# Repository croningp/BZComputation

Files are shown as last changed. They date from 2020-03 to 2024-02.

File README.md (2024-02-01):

# A Programmable Hybrid Digital Chemical Information Processor based on the Belousov-Zhabotinsky Reaction



This repository consist of the hardware and specification of parts associated to the paper "A Programmable Hybrid Digital Chemical Information Processor based on the Belousov-Zhabotinsky Reaction".

Authors: Abhishek Sharma, Marcus Tze-Kiat Ng, Juan Manuel Parrilla Gutierrez, Yibin Jiang, Leroy Cronin*

School of Chemistry, The University of Glasgow, University Avenue, Glasgow G12 8QQ, United Kingdom

## Platform Overview
The periodicity of the oscillation of the BZ reaction is controlled via mechanical stimulus from the magnetics stirrers. On top of that, the coupling between two or more neighbouring cells are governed by the hydrodynamics through the interfacial stirrers.<br/>
The dimension of each cell was desgined in such a way that no apparent coupling between cells can be observed without activation of the interfacial stirrers.
<p align="center">
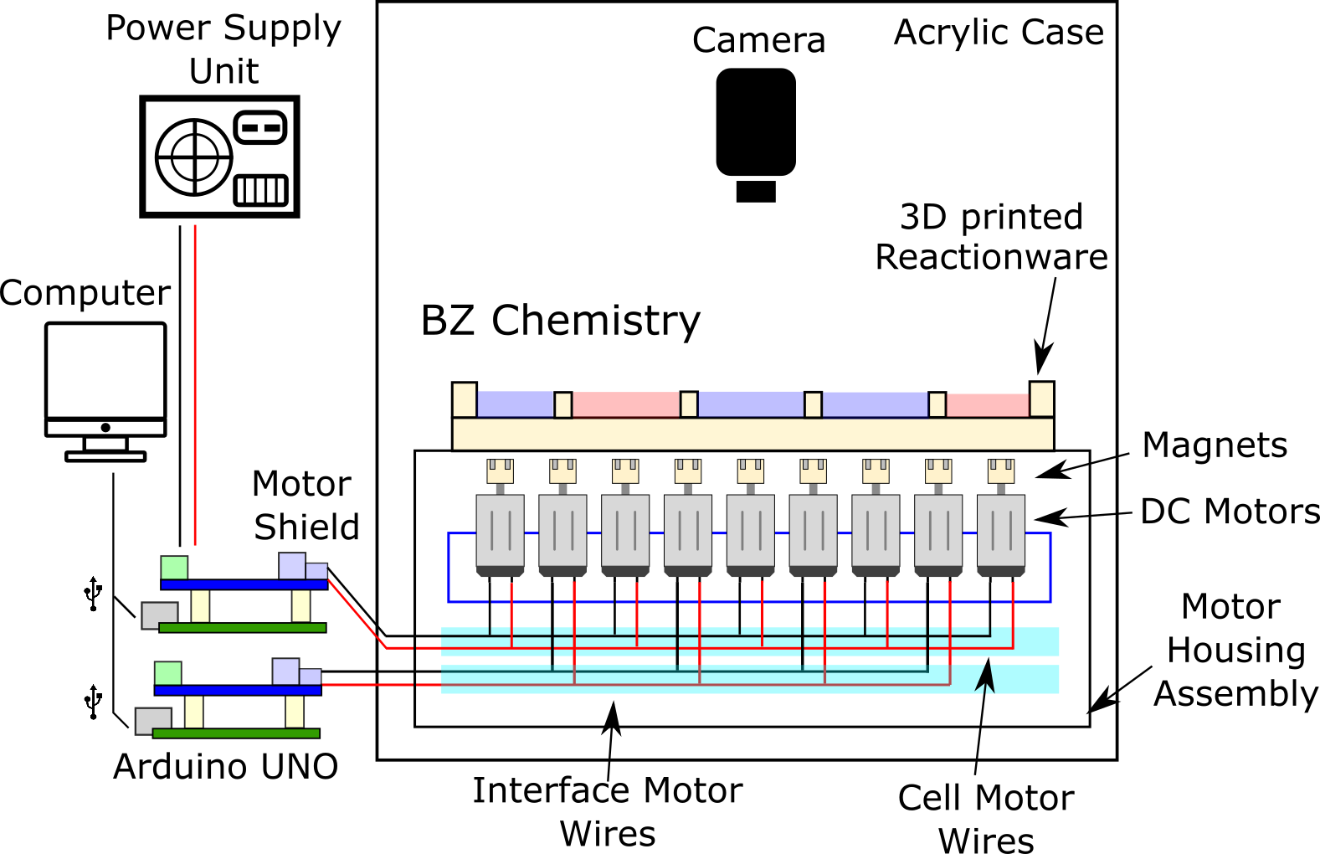
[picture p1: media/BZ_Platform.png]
  

Details regarding the hardware and the STLs of the 3D printed parts used for the experiments are provided in [hardware](https://github.com/croningp/BZComputation/blob/master/hardware/hardware.md).

## Basic Experimental Control Code example
```python
# Library imports
import cv2
import sys
import time
import queue
import random
import numpy as np

from tricont_ctonrols import TricontControl
from bz_control import BZBoard
import predict_cnn_2D

resq = multiprocessing.Queue()
stopt = multiprocessing.Queue()

cnn = predict_cnn_2D.CNN(kwargs={
	'streampath': "invideo", 'outvideo': "output",
	'resq': resq, 'stopsig': stopt
	})

# Microcontroller Names (Arduino UNOs)
arduino_dict= {         
		0: "/dev/BZ_satu",
		1: "/dev/BZ_dua",
		2: "/dev/BZ_tiga",
		3: "/dev/BZ_empat"  }

b = BZBoard(port_dict=arduino_dict)    # Arduino device
p = TricontControl()                   # Calling Tricontinent pumps 
'''
Pretreatment before starting an experiment which includes filling the platform with the BZ
solutions and mixing/stabilisation period which allow the solution to be spread evenly 
throughout the platform.
 '''
p.filling_2d()
b.activate_all(speed=50)
time.sleep(60)
b.disable_all()
time.sleep(240)

# Start of experiment
cnn.start()
'''
Conditions provided which is unique to the experiments depending on what is required.
In this particular example the experiment will stay put for a minute and terminate the experiment.
'''
time.sleep(60)

# End of experiment
stopt.put(1)
cnn.join()
	
p.cleaning_2d()
```

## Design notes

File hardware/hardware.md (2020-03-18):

# Hardware

The 3D printed parts (.stl) were desgined with Onshape.<br/>
Both of the platforms are covered with opaque arcylic sheets to minimise reflection of the solution from direct light.

## Liquid Handling

All the pumps operated were from [Tricontinent C-Series Syringe Pumps](https://www.gardnerdenver.com/en-gb/tricontinent/c-series-syringe-pumps) with T Valve 3-port. The [syringes](https://www.gardnerdenver.com/en-gb/tricontinent/syringes) used were 5 ml for the ferroin indicator and 12.5 ml for the rest of the solutions. The tubes were 1/8 in PTFE Tubing.<br/>
Fully documented Tricontinent Pump controller can be found in: https://github.com/croningp/pycont

## DC motors 
The DC motors are separated into two categories, namely: <br/>
(i) [Cell-motors](https://uk.rs-online.com/web/p/dc-geared-motors/8347675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) <br/>
(ii) [Interface-motors](https://www.aliexpress.com/item/32780746288.html)<br/>
The motors are then coupled with the magnet holders which then allow the magnetic stirrers to be controlled by modulating the PWM signal generated by the electronics.<br/>
The cell-motors were stirred in clockwise manner whilst the interface-motors were stirred in anti-clockwise to ensure the bidirectional flow of the solutions.

## Imaging platform 
Cameras used in both platforms are [logitech C920 HD PRO WEBCAM](https://www.logitech.com/en-gb/product/hd-pro-webcam-c920) <br/>
The height of the cameras from the experimental platforms are as followed:<br/>
1D Platform: 20.5 cm <br/>
2D Platform: 33.4 cm <br/>
This ensures the total coverage of the platform evenly.

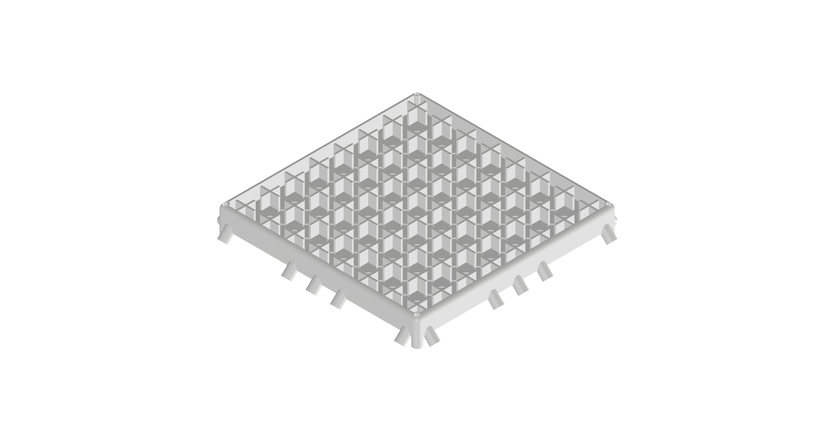
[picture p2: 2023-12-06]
hardware/CAD_Designs/pngs/2D_top.png

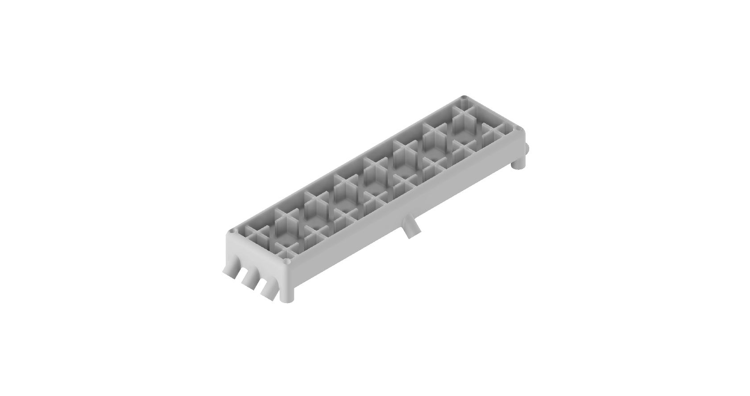
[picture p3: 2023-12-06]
hardware/CAD_Designs/pngs/1D_top.png

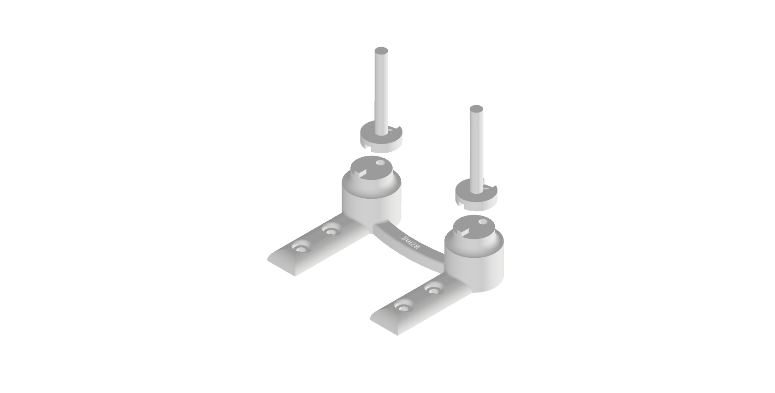
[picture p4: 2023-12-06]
hardware/CAD_Designs/pngs/1D_column.png

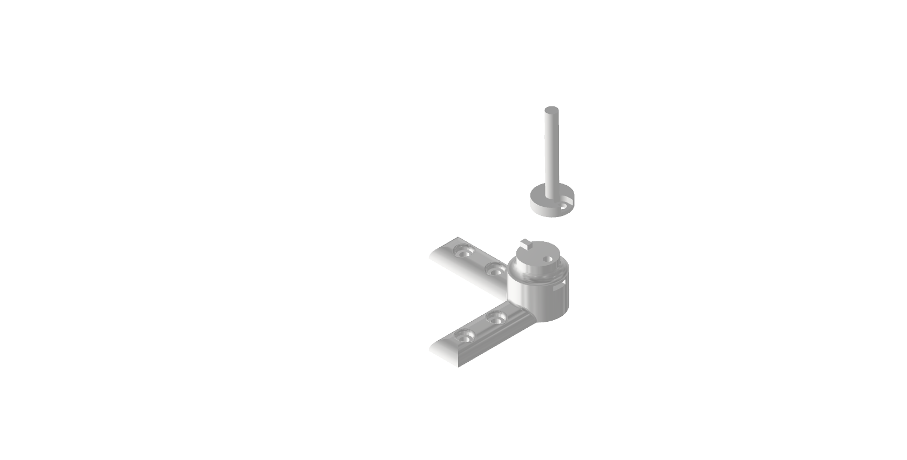
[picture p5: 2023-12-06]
hardware/CAD_Designs/pngs/2D_column.png

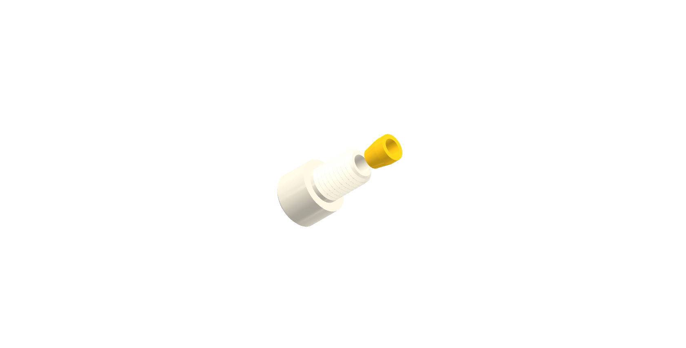
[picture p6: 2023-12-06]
hardware/CAD_Designs/pngs/nut_ferrules.png

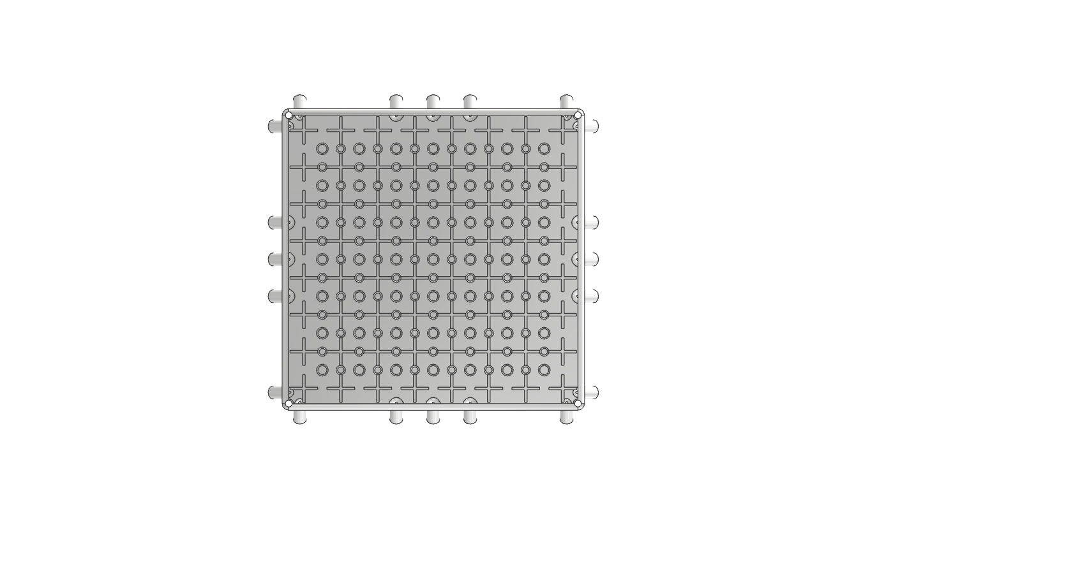
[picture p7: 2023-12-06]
hardware/CAD_Designs/pngs/2D_top_view.png

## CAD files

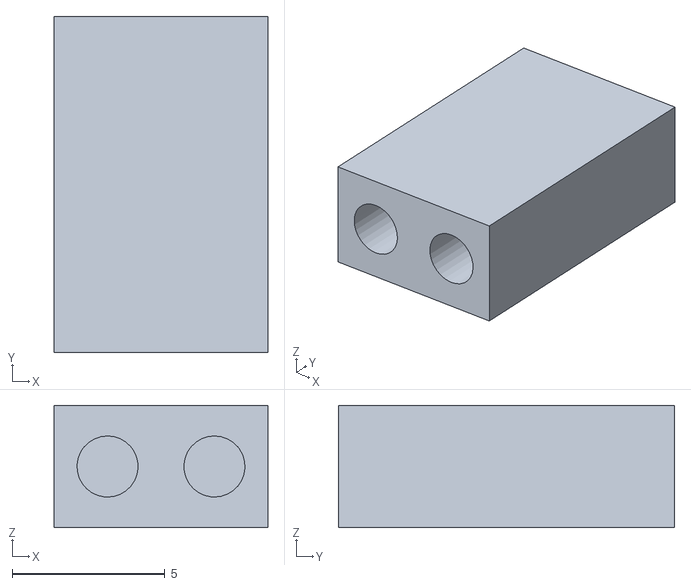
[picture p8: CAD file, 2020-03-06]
hardware/STL_Files/magnet_holder_b.stl
7.00 x 11.0 x 4.00

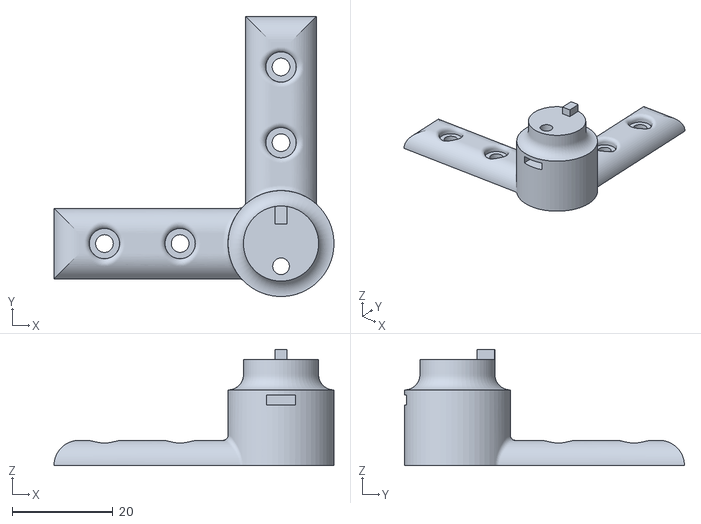
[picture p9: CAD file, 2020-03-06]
hardware/STL_Files/2d_stand.stl
55.5 x 55.5 x 23.0

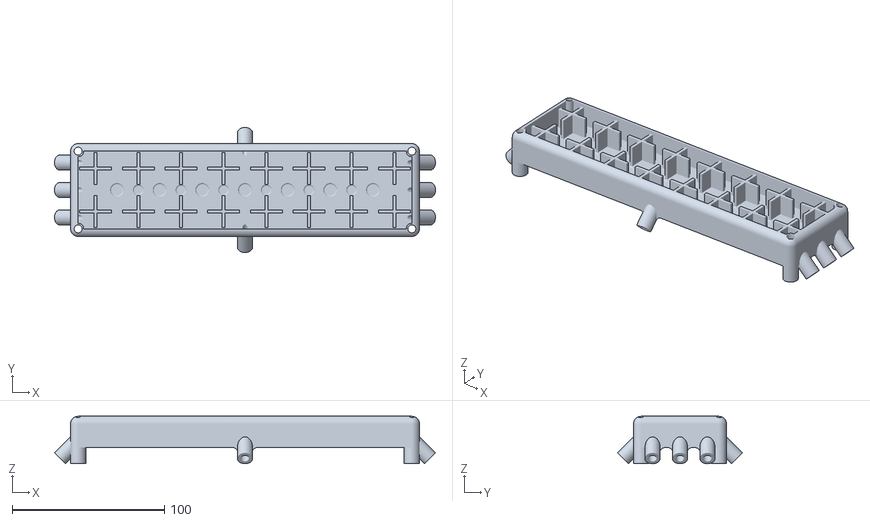
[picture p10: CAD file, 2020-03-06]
hardware/STL_Files/1d_top.stl
250.1 x 82.1 x 31.2

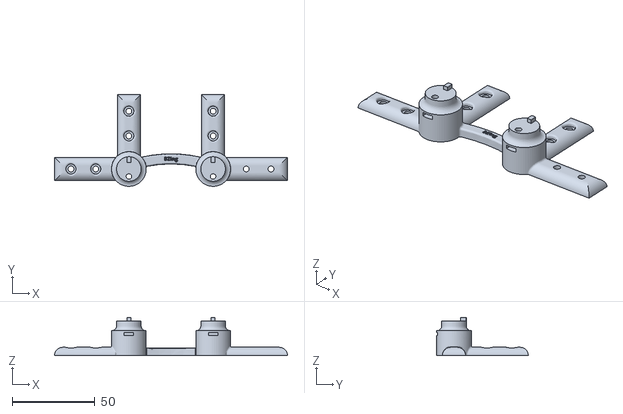
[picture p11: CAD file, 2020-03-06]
hardware/STL_Files/1d_stand.stl
141.0 x 55.5 x 23.0

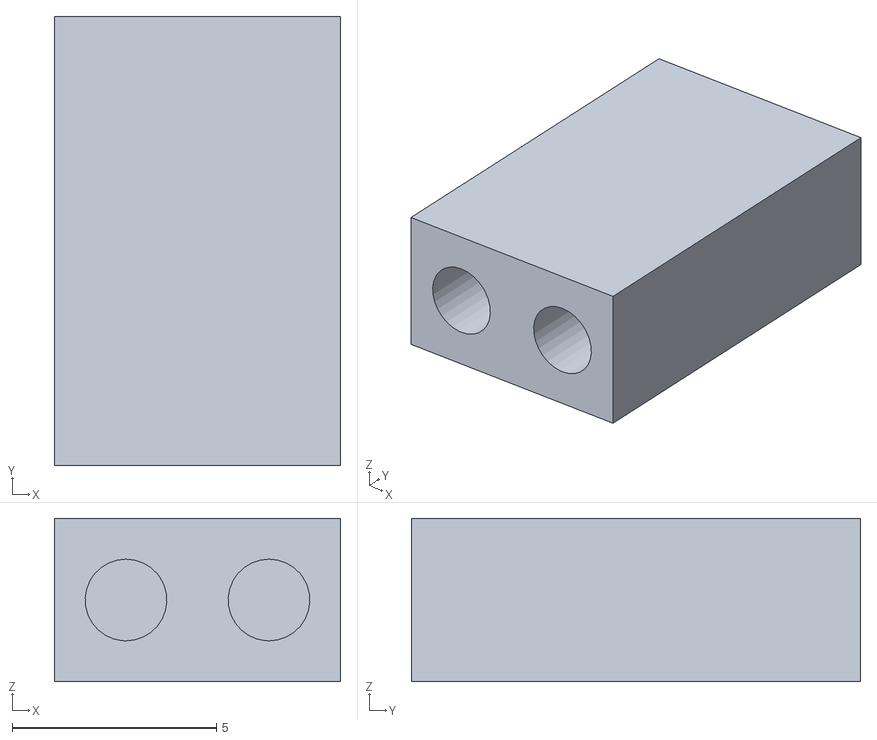
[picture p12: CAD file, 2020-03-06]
hardware/STL_Files/magnet_holder_a.stl
7.00 x 11.0 x 4.00

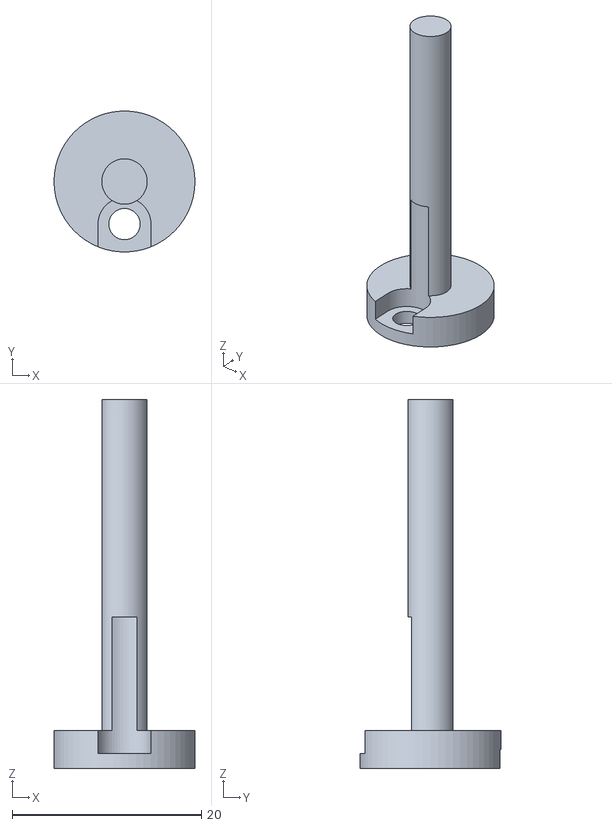
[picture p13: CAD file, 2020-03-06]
hardware/STL_Files/column.stl
14.9 x 14.9 x 39.0

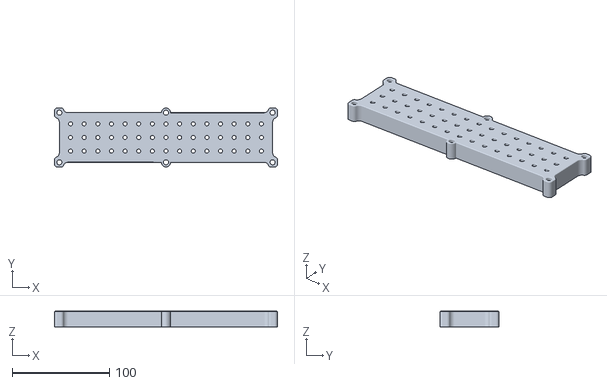
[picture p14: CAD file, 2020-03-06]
hardware/STL_Files/1d_bottom.stl
229.0 x 61.0 x 16.0

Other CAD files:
hardware/CAD_Designs/1D/1D_overall_new.dwg
hardware/CAD_Designs/1D/1D_motors_n_magnet.dwg
hardware/CAD_Designs/2D/motor and magnet.dwg
hardware/CAD_Designs/2D/BZ_CA_2D_base.dwg
hardware/CAD_Designs/1D/1D_top.dwg
hardware/CAD_Designs/2D/Column 2D.dwg
hardware/CAD_Designs/1D/1D_stand_n_spacer.dwg
hardware/CAD_Designs/2D/2D_CA_Automated_real.dwg
hardware/CAD_Designs/1D/1D_bottom.dwg

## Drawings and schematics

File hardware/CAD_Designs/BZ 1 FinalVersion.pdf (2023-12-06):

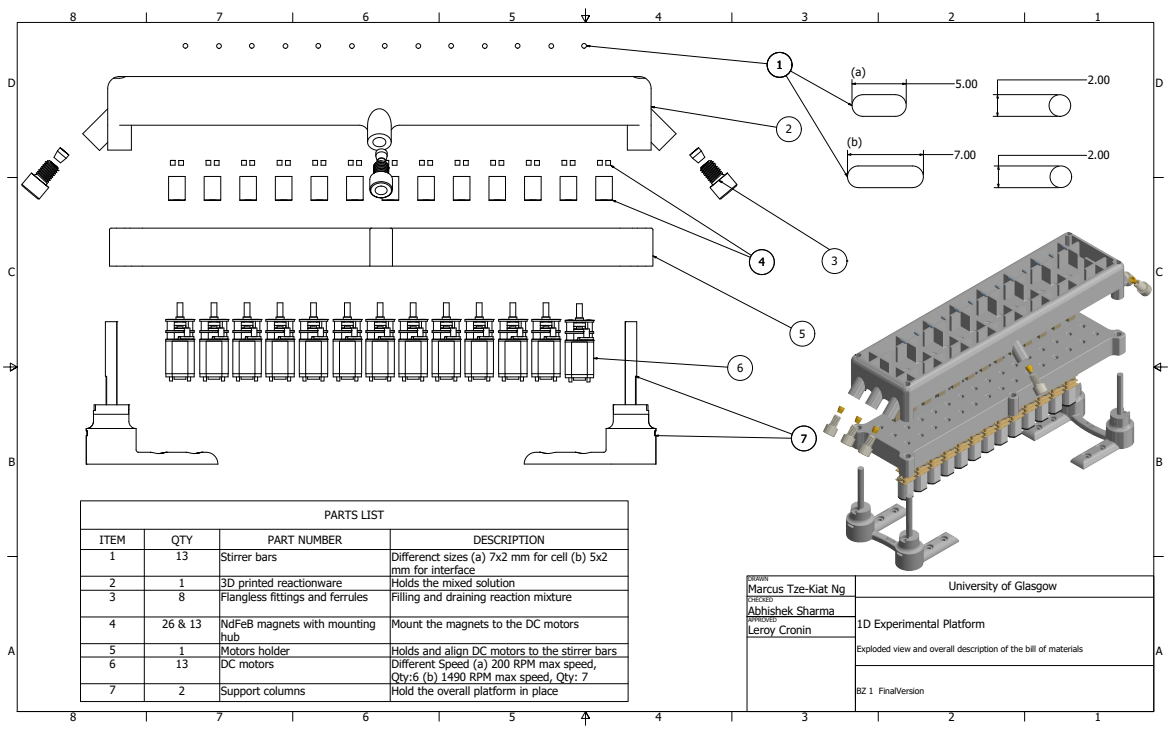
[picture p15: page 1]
PARTS LIST; 3D printed reactionware; Holds the mixed solution; NdFeB magnets with mounting; Mount the magnets to the DC motors; Leroy Cronin; BZ 1 FinalVersion

ITEM | QTY | PART NUMBER | DESCRIPTION
1 | 13 | Stirrer bars | Differenct sizes (a) 7x2 mm for cell (b) 5x2 mm for interface

DRAWN
Marcus Tze-Kiat Ng

University of Glasgow

3 | 8 | Flangless fittings and ferrules | Filling and draining reaction mixture

CHECKED Abhishek Sharma | 1D Experimental Platform Exploded view and overall description of the bill of materials

5 | 1 | Motors holder | Holds and align DC motors to the stirrer bars
6 | 13 | DC motors | Different Speed (a) 200 RPM max speed, Qty:6 (b) 1490 RPM max speed, Qty: 7

7 | 2 | Support columns | Hold the overall platform in place

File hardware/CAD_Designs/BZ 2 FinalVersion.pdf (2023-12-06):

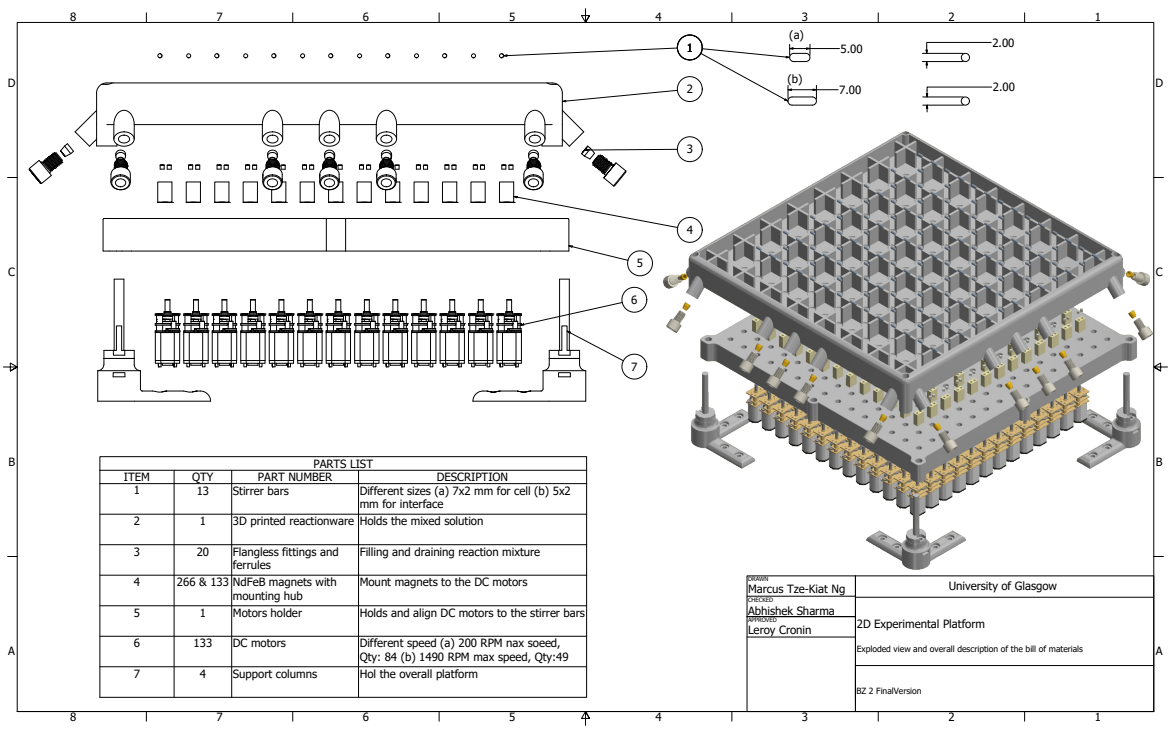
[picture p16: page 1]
PARTS LIST; ITEM; QTY; PART NUMBER; DESCRIPTION; Stirrer bars; 3D printed reactionware Holds the mixed solution; Flangless fittings and; Filling and draining reaction mixture; NdFeB magnets with; Mount magnets to the DC motors; mounting hub; Motors holder; Holds and align DC motors to the stirrer bars; DC motors; Support columns; Hol the overall platform; 2D Experimental Platform; BZ 2 FinalVersion; Abhishek Sharma; Leroy Cronin

Different sizes (a) 7x2 mm for cell (b) 5x2
mm for interface

DRAWN
Marcus Tze-Kiat Ng

University of Glasgow

Different speed (a) 200 RPM nax soeed,
Qty: 84 (b) 1490 RPM max speed, Qty:49

Exploded view and overall description of the bill of materials

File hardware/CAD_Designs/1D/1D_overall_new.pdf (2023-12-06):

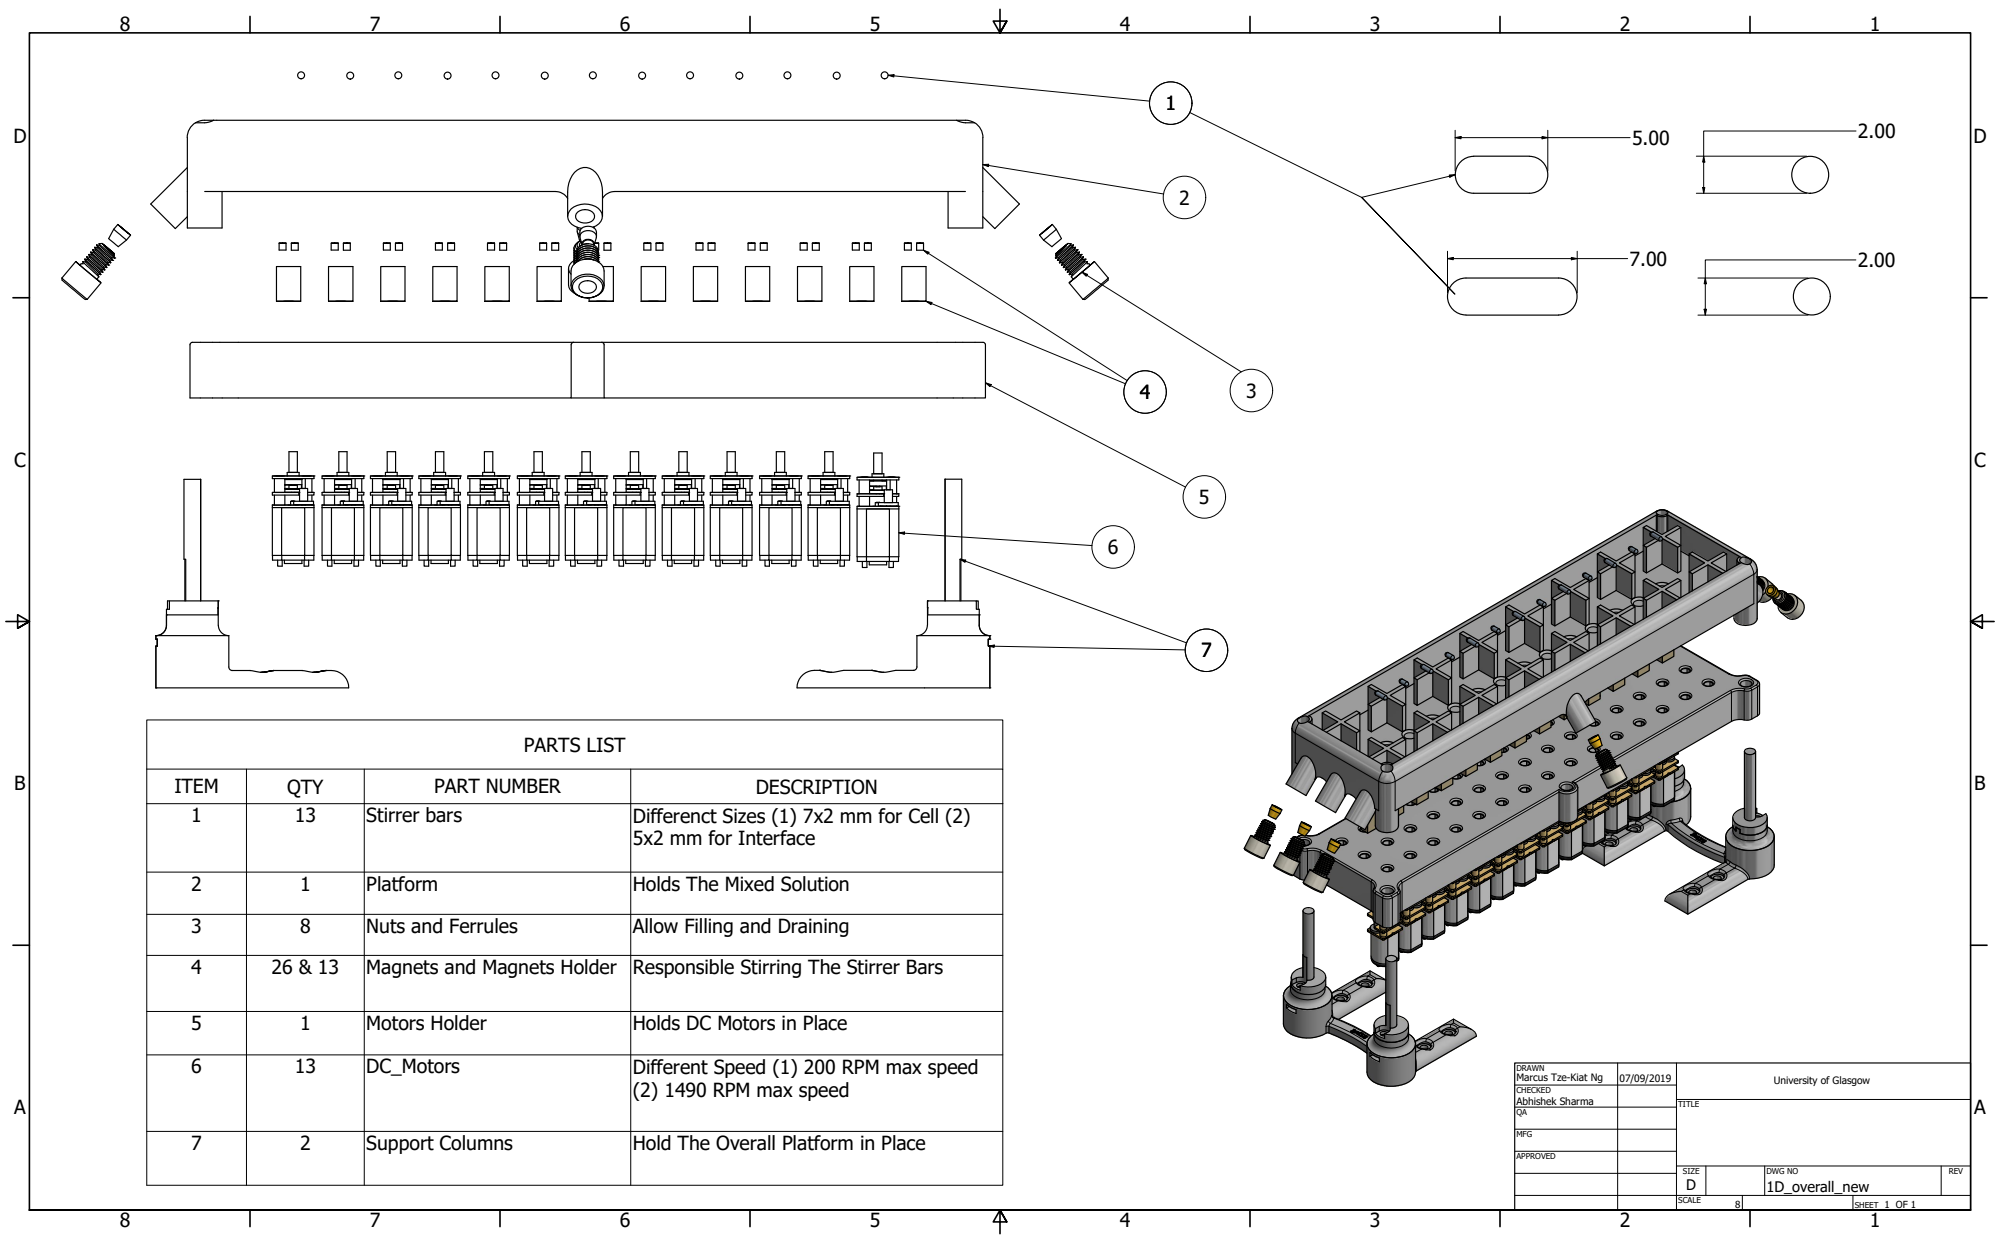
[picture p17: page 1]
PARTS LIST

ITEM | QTY | PART NUMBER | DESCRIPTION
1 | 13 | Stirrer bars | Differenct Sizes (1) 7x2 mm for Cell (2) 5x2 mm for Interface

2 | 1 | Platform | Holds The Mixed Solution

3 | 8 | Nuts and Ferrules | Allow Filling and Draining

4 | 26 & 13 | Magnets and Magnets Holder | Responsible Stirring The Stirrer Bars

5 | 1 | Motors Holder | Holds DC Motors in Place

6 | 13 | DC_Motors | Different Speed (1) 200 RPM max speed (2) 1490 RPM max speed

DRAWN Marcus Tze-Kiat Ng | 07/09/2019 | University of Glasgow

CHECKED Abhishek Sharma

MFG

7 | 2 | Support Columns | Hold The Overall Platform in Place

APPROVED

SIZE D | DWG NO 1D_overall_new | REV

SCALE 8 | | SHEET 1 OF 1

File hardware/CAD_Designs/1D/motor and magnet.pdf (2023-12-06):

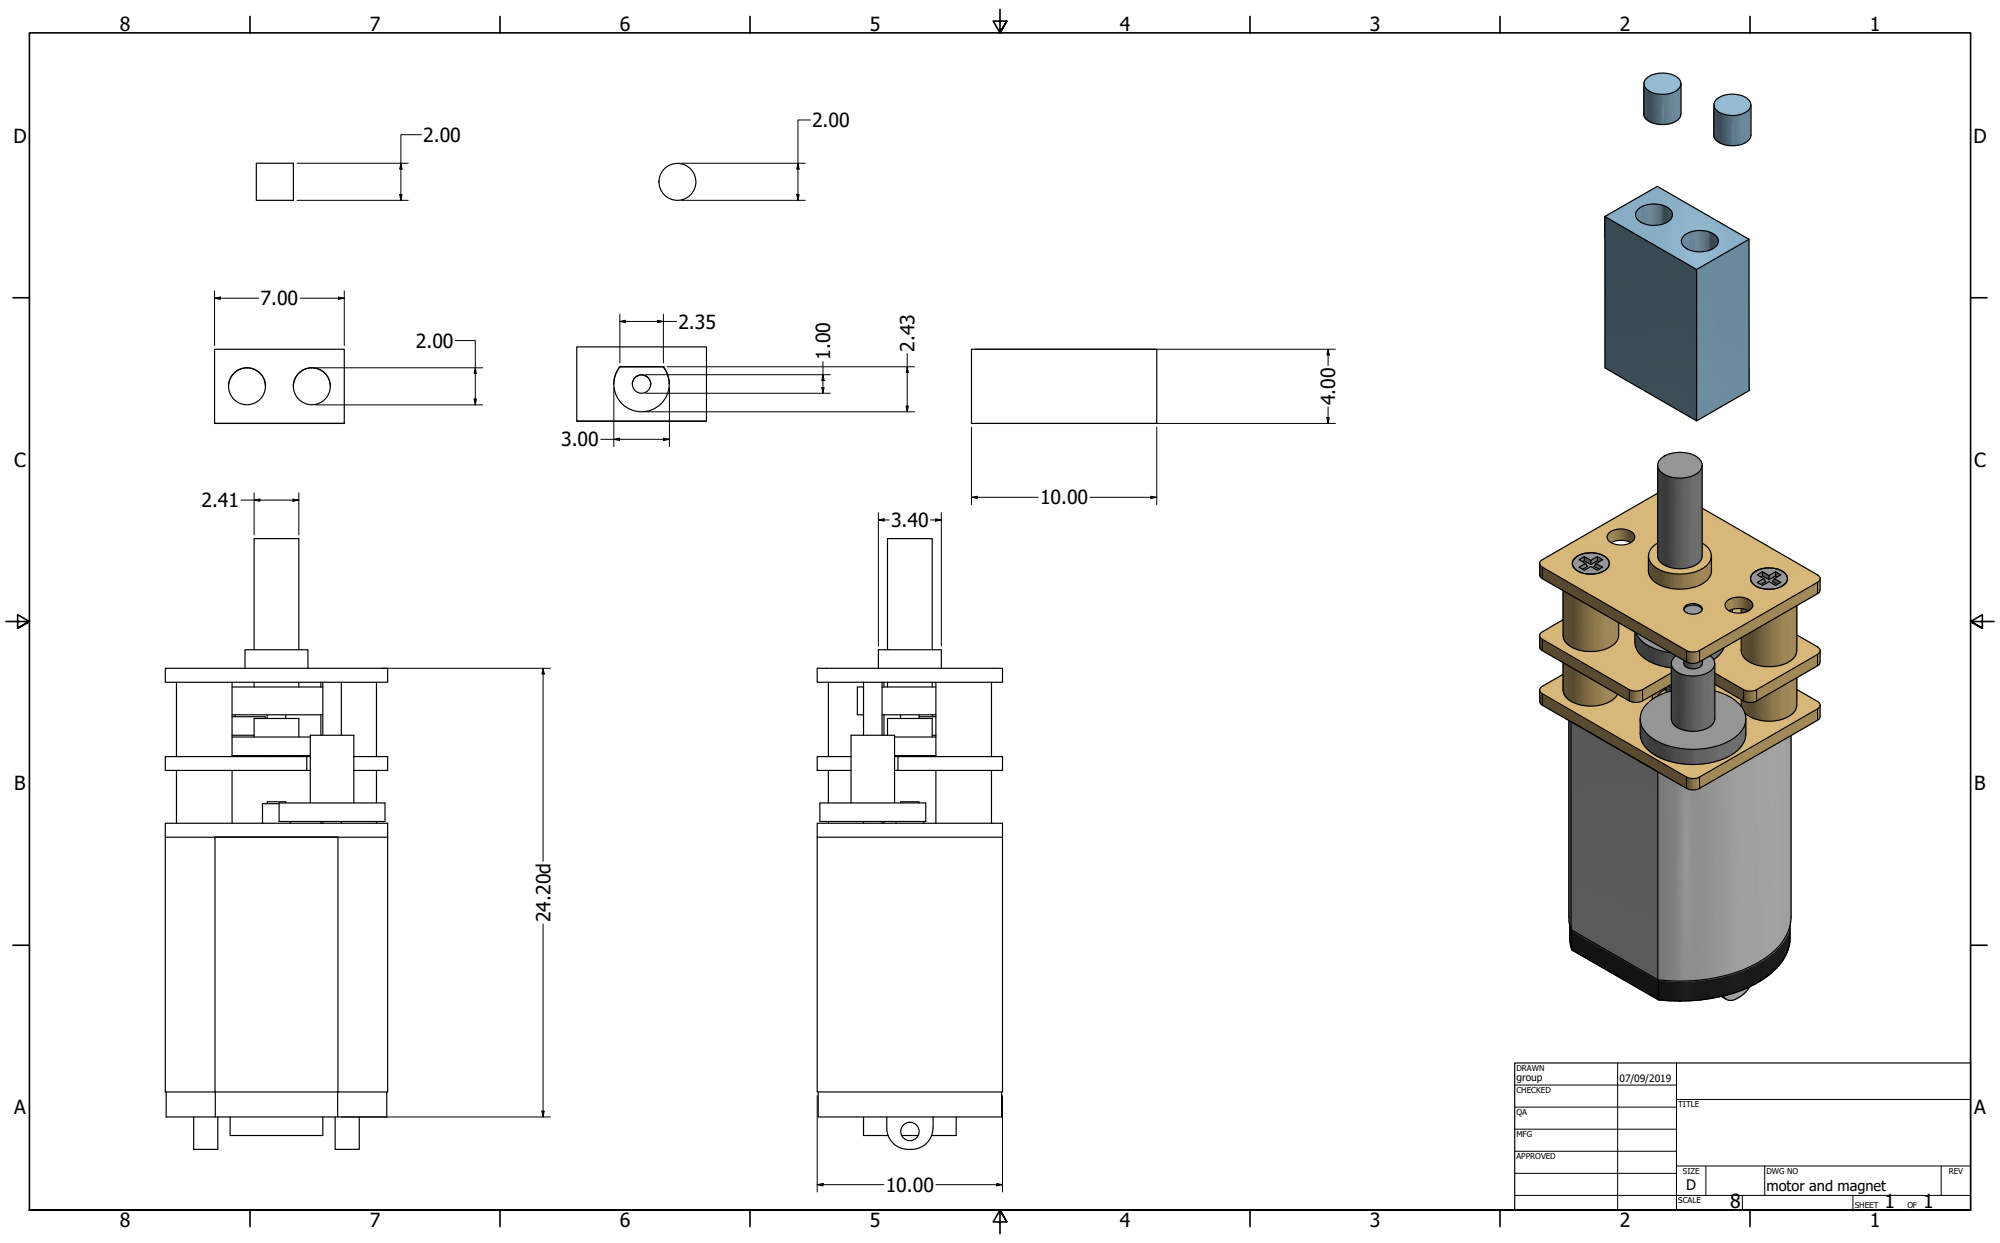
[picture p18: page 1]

DRAWN group | 07/09/2019

CHECKED

MFG

APPROVED

SIZE D | DWG NO motor and magnet | REV

8 SCALE | | SHEET 1 OF 1

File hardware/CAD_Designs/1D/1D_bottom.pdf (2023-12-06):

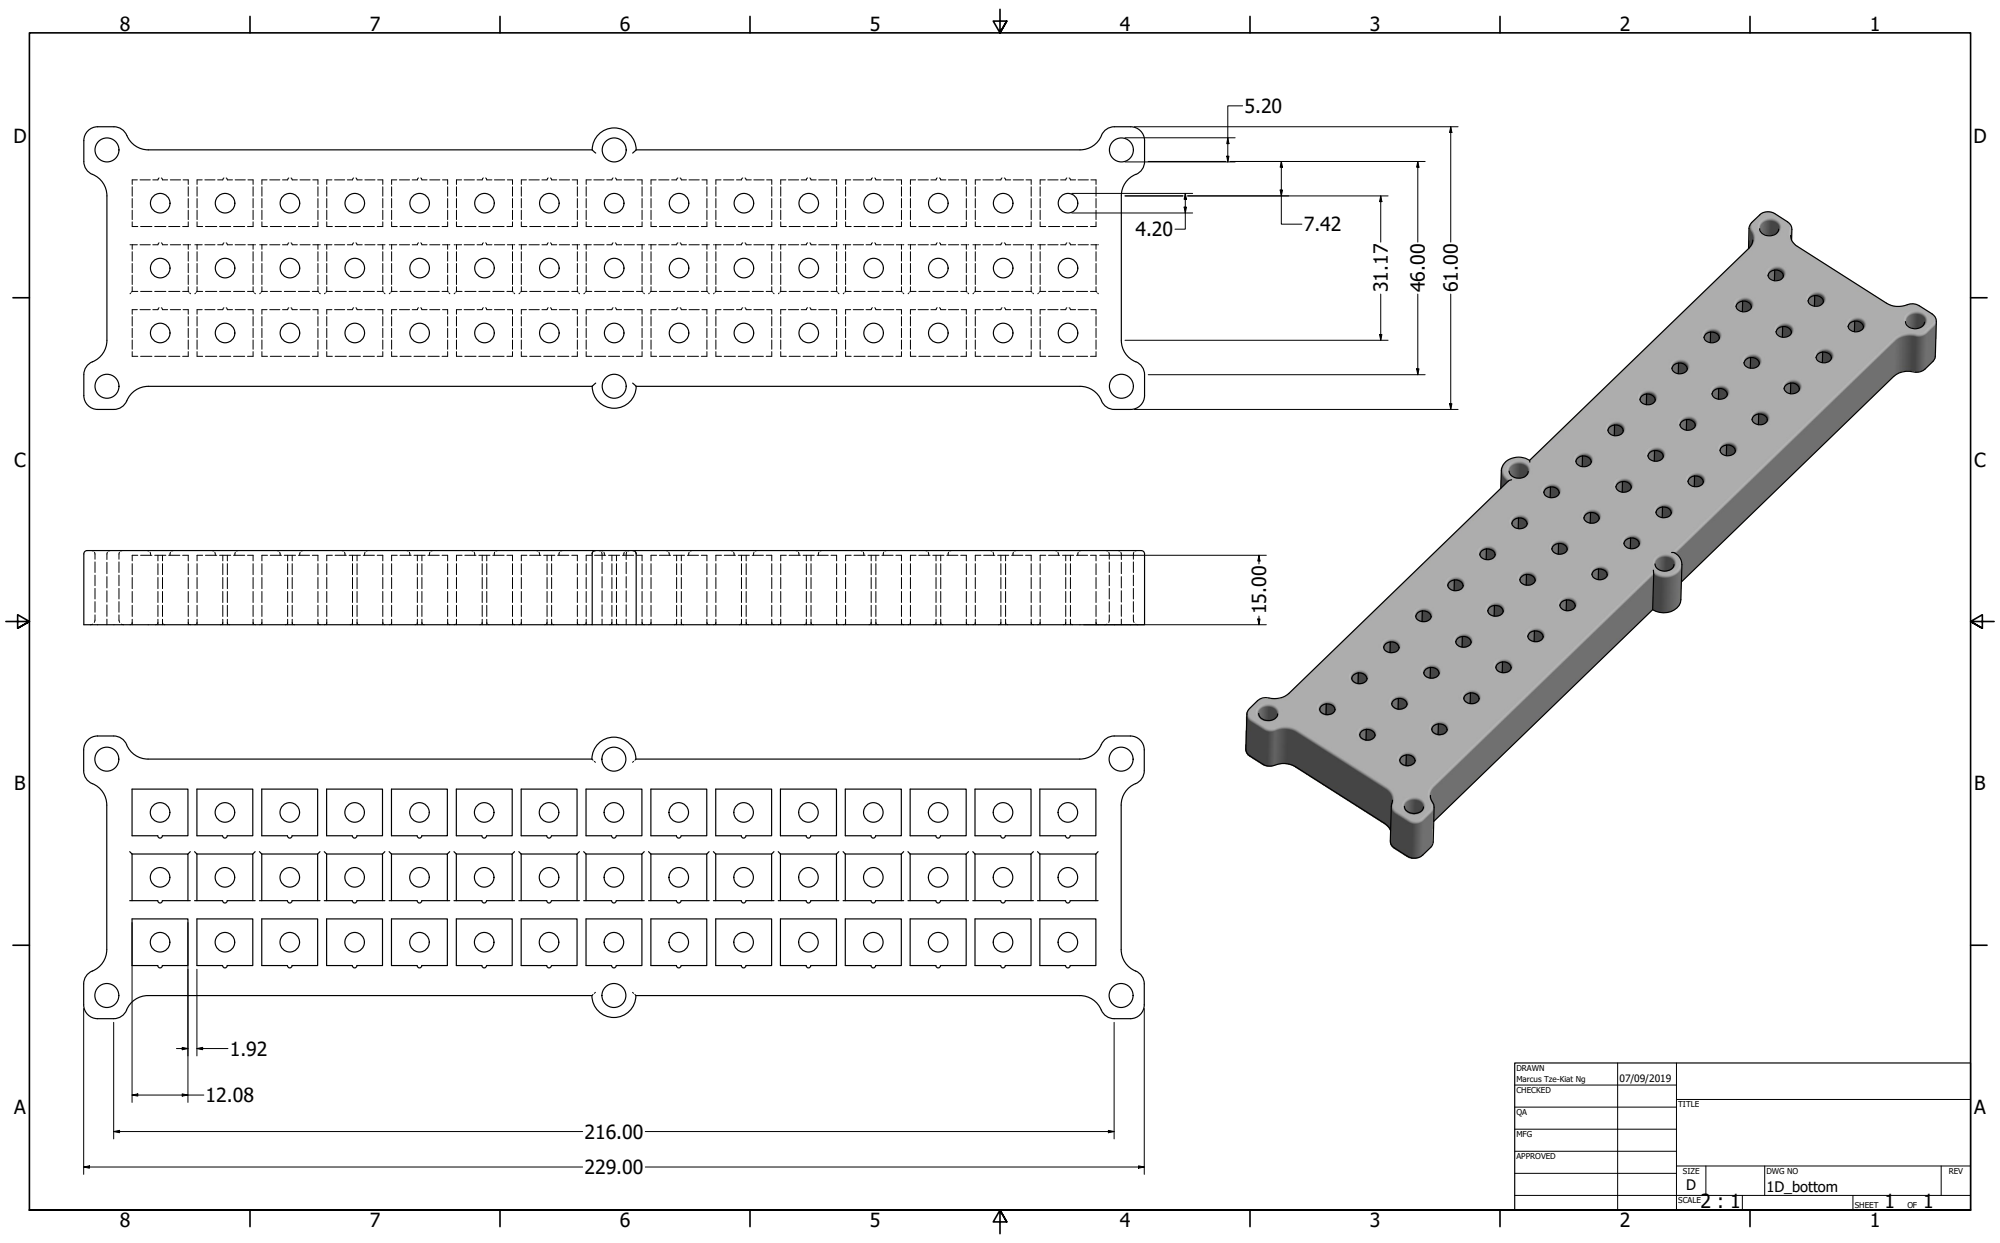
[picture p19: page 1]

DRAWN Marcus Tze-Kiat Ng | 07/09/2019

CHECKED

MFG

APPROVED

SIZE D | DWG NO 1D_bottom | REV

2 : 1 SCALE | | SHEET 1 OF 1

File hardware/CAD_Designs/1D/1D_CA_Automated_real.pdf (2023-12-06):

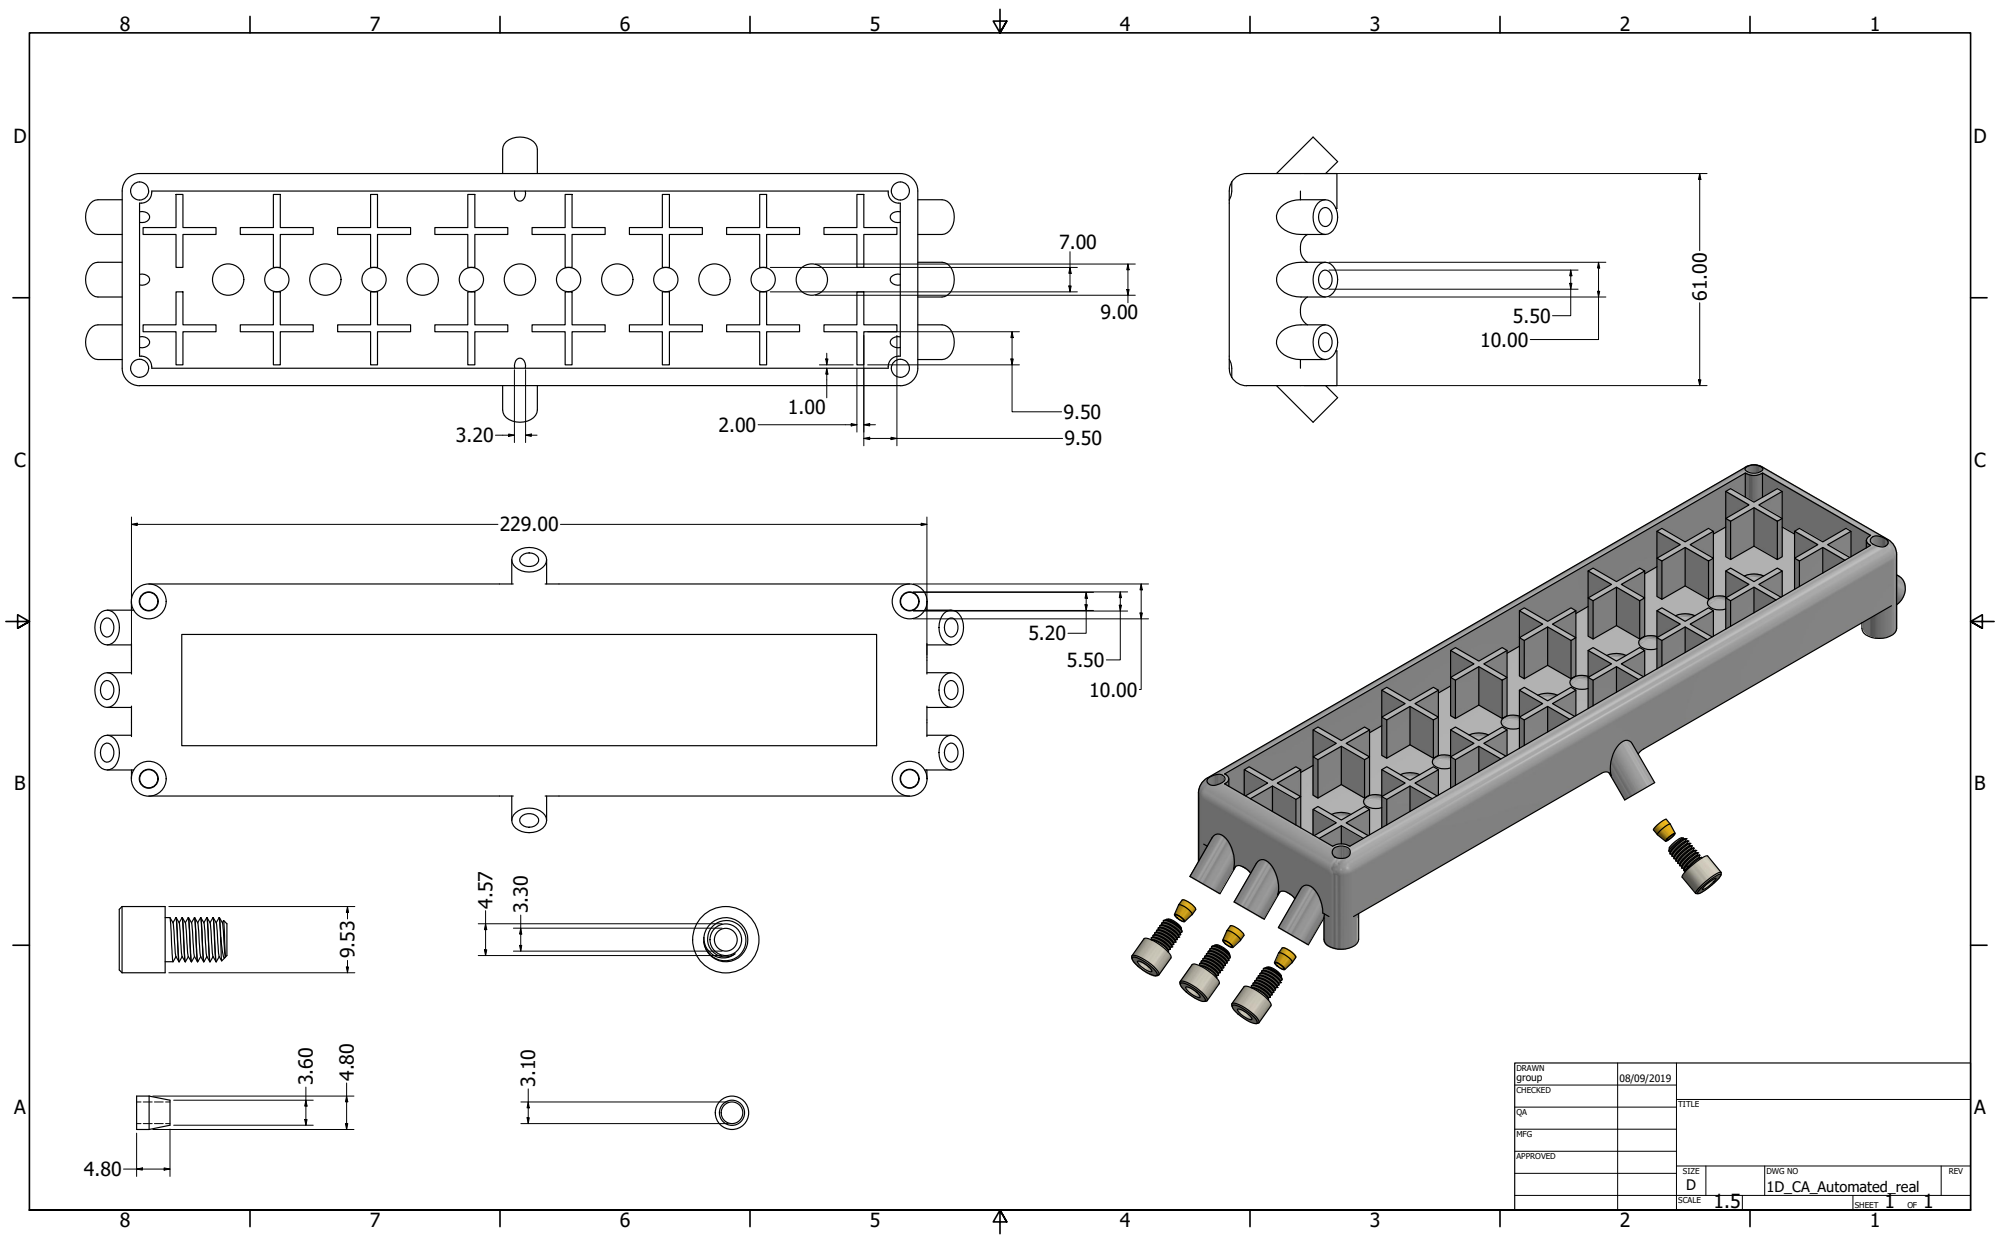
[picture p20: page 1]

al TITLE SIZE DSCALE

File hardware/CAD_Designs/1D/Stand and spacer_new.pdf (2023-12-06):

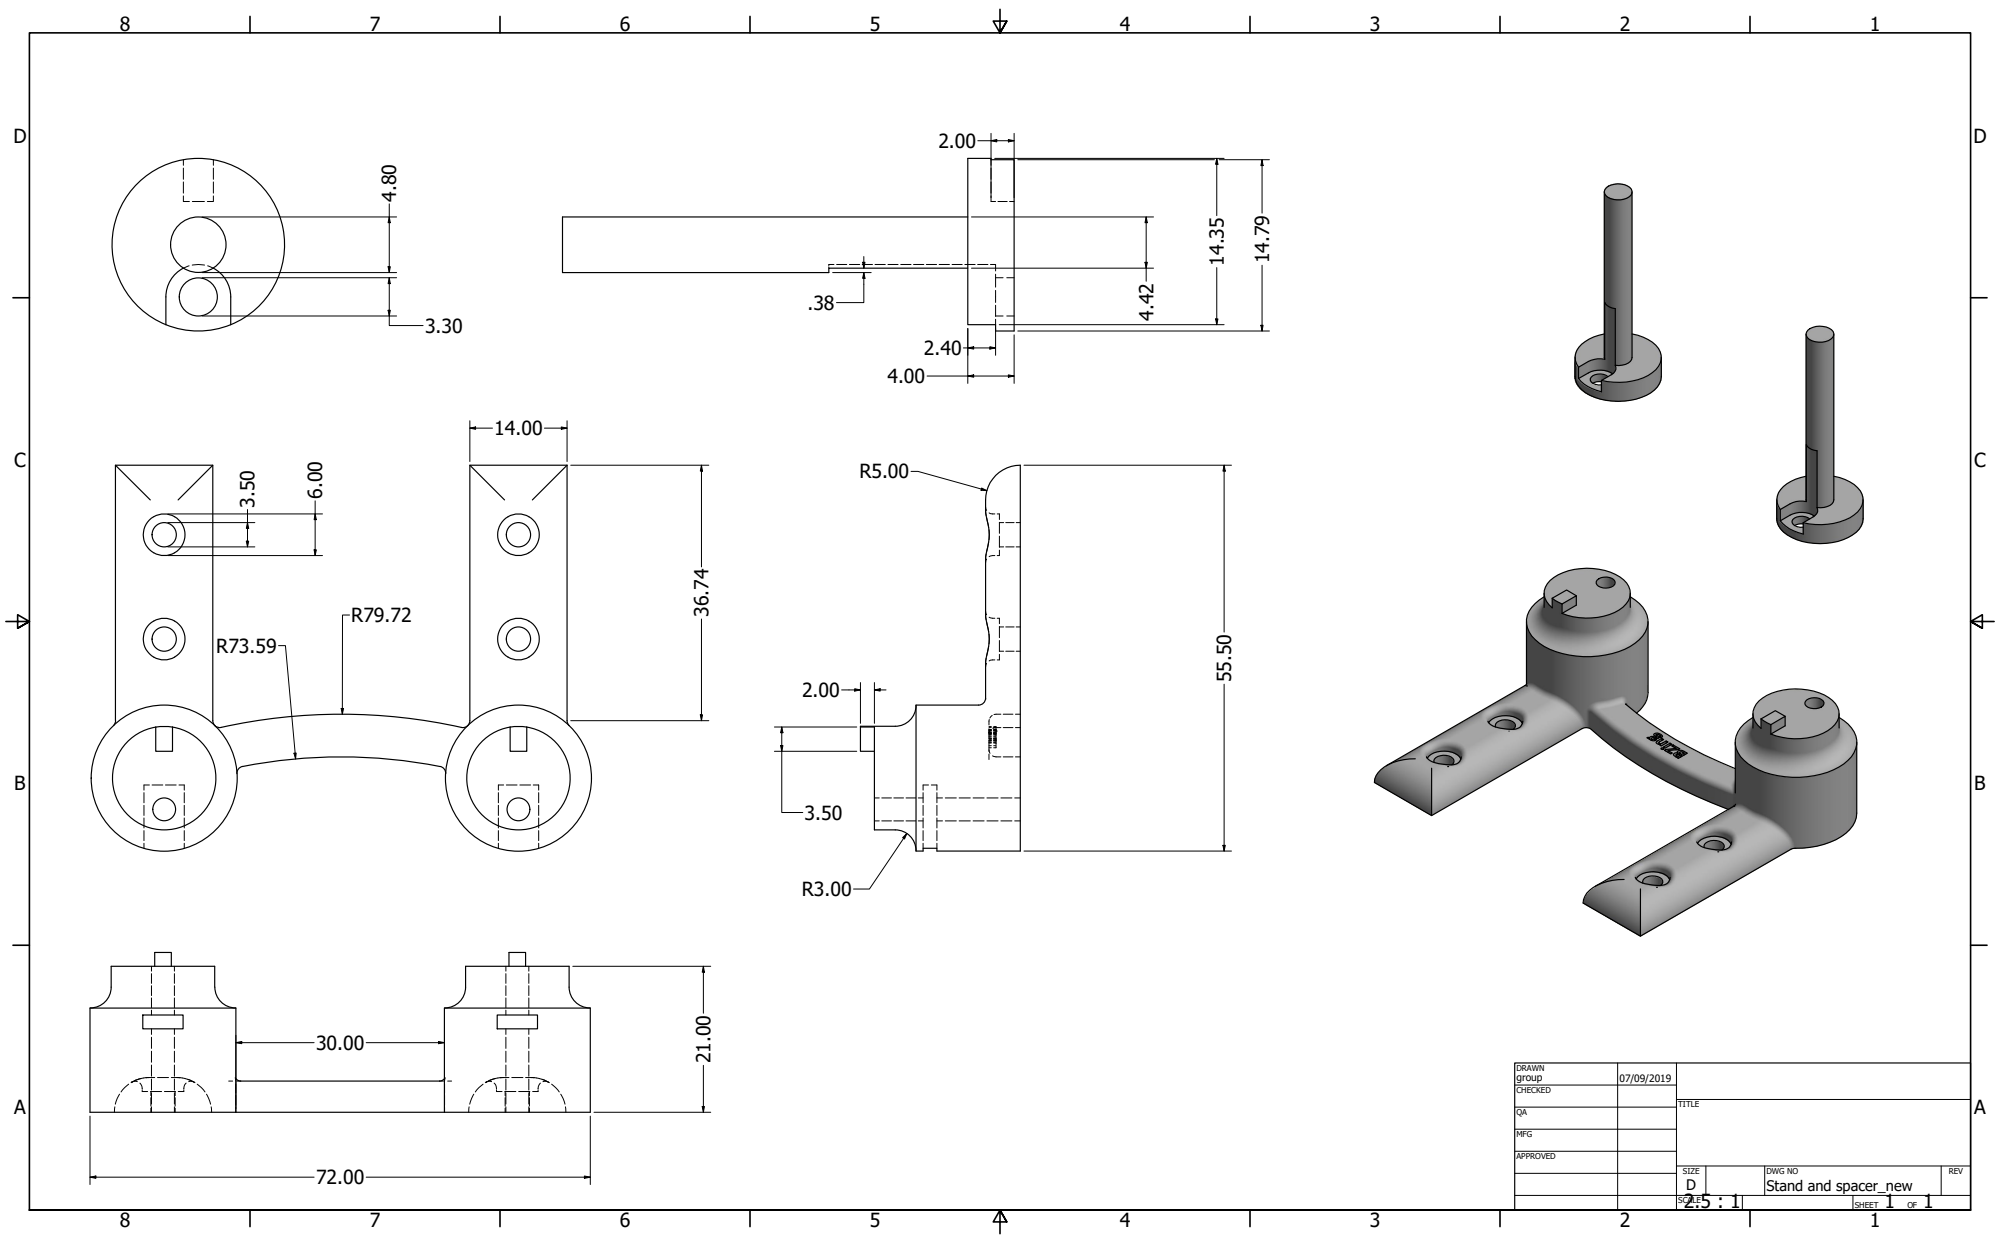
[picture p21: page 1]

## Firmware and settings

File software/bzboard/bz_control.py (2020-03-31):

# ---------------------------------------------------------------------------- #
# --------------- TWO DIMENSIONAL BZ PLATFORM 7 X 7 CONTROLLER --------------- #
# ---------------------------------------------------------------------------- #


"""
	Controls BZ Board using Serial Interface. Each motor can be addressed individually.
	Each cell: C has four interfacial stirrers: I in all four sides except for the ones at 
	the edges and corners.
	

	Cell Stirrers in 7x7 array are given by : 

	+ --------------------------------------------+
	|											  |
	|	C17	  C27   C37   C47   C57   C67   C77	  |
	|											  |
	|	C16   C26   C36   C46   C56   C66   C76   |
	|											  |
	|	C15	  C25	C35	  C45	C55	  C65	C75   |
	|											  |
	|	C14   C24	C34	  C44	C54	  C64	C74   |
	|											  |
	|	C13	  C23	C33	  C43	C53	  C63	C73   |
	|											  |
	|	C12	  C22	C32	  C42	C52	  C62	C72   |
	|											  |
	|	C11	  C21	C31	  C41	C51	  C61	C71   |
	|											  |
	+---------------------------------------------+

"""

import os
import time
import json
import random
import serial

class BZBoard:
	"""
		Base Class to control all the motors via four connected Arduino UNOs.
	"""


	def __init__(self, port_dict):
		random.seed(37)
		"""
			Initialized BZ Board, Serial Communication with Arduino UNOs.
		"""

		self.ncells_X, self.ncells_Y = 7, 7

		self.ser = {}
		for n, port in port_dict.items():
			self.ser[n] = serial.Serial(port, 9600, timeout=120)
		
		time.sleep(2) # serial docs recommend a wait just after connection
		for serial_obj in self.ser.values():
			serial_obj.flush()
			serial_obj.flushInput()
			serial_obj.flushOutput()


		# List of all Cell Stirrers
		# [arduino_numer, adafruit_shield, motor] 
		
		self.cell_motors = { 

			# Port_1(satu): CONTROLS CELL STIRRERS
			# ----------------------------------------------------------------------- #

			"C11": [0, 0, 1], "C21": [0, 0, 2], "C31": [0, 0, 3], "C41": [0, 0, 4],
			"C12": [0, 1, 1], "C22": [0, 1, 2], "C32": [0, 1, 3], "C42": [0, 1, 4],
			"C13": [0, 2, 1], "C23": [0, 2, 2], "C33": [0, 2, 3], "C43": [0, 2, 4],
			"C14": [0, 3, 1], "C24": [0, 3, 2], "C34": [0, 3, 3], "C44": [0, 3, 4],
			"C15": [0, 4, 1], "C25": [0, 4, 2], "C35": [0, 4, 3], "C45": [0, 4, 4],
			"C16": [0, 5, 1], "C26": [0, 5, 2], "C36": [0, 5, 3], "C46": [0, 5, 4],
			"C17": [0, 6, 1], "C27": [0, 6, 2], "C37": [0, 6, 3], "C47": [0, 6, 4],

			# Port_2(dua): CONTROLS CELL STIRRERS
			# ----------------------------------------------------------------------- #

			"C51": [1, 0, 1], "C61": [1, 0, 2], "C71": [1, 0, 3],
			"C52": [1, 1, 1], "C62": [1, 1, 2], "C72": [1, 1, 3],
			"C53": [1, 2, 1], "C63": [1, 2, 2], "C73": [1, 2, 3],
			"C54": [1, 3, 1], "C64": [1, 3, 2], "C74": [1, 3, 3],
			"C55": [1, 4, 1], "C65": [1, 4, 2], "C75": [1, 4, 3],
			"C56": [1, 5, 1], "C66": [1, 5, 2], "C76": [1, 5, 3],
			"C57": [1, 6, 1], "C67": [1, 6, 2], "C77": [1, 6, 3],
		}

		# List of all Interfacial Stirrers
		# [arduino_numer, adafruit_shield, motor] 

		self.interface_motors = {

			# Port_3(tiga): CONTROLS INTERFACIAL STIRRERS
			# ----------------------------------------------------------------------- #

			"I11": [2, 0, 1], "I12": [2, 0, 2], "I13": [2, 0, 3], "I14": [2, 0, 4],
			"I15": [2, 1, 1], "I16": [2, 1, 2], "I17": [2, 1, 3], "I18": [2, 1, 4],
			"I19": [2, 2, 1], "I110": [2, 2, 2], "I111": [2, 2, 3], "I112": [2, 2, 4],
			"I21": [2, 3, 1], "I22": [2, 3, 2], "I23": [2, 3, 3], "I24": [2, 3, 4],
			"I25": [2, 4, 1], "I26": [2, 4, 2], "I27": [2, 4, 3], "I28": [2, 4, 4],
			"I29": [2, 5, 1], "I210": [2, 5, 2], "I211": [2, 5, 3], "I212": [2, 5, 4],
			"I31": [2, 6, 1], "I32": [2, 6, 2], "I33": [2, 6, 3], "I34": [2, 6, 4],
			"I35": [2, 7, 1], "I36": [2, 7, 2], "I37": [2, 7, 3], "I38": [2, 7, 4],
			"I39": [2, 8, 1], "I310": [2, 8, 2], "I311": [2, 8, 3], "I312": [2, 8, 4],
			"I113": [2, 9, 1], "I213": [2, 9, 2], "I313": [2, 9, 3],
			"I48": [2, 10, 1], "I410": [2, 10, 2], "I412": [2, 10, 3],

			# Port_4(empat): CONTROLS INTERFACIAL STIRRERS
			# ----------------------------------------------------------------------- #

			"I41": [3, 0, 1], "I42": [3, 0, 2], "I43": [3, 0, 3], "I44": [3, 0, 4],
			"I45": [3, 1, 1], "I46": [3, 1, 2], "I47": [3, 1, 3],
			"I49": [3, 2, 1], "I411": [3, 2, 2], "I413": [3, 2, 3],
			"I51": [3, 3, 1], "I52": [3, 3, 2], "I53": [3, 3, 3], "I54": [3, 3, 4],
			"I55": [3, 4, 1], "I56": [3, 4, 2], "I57": [3, 4, 3], "I58": [3, 4, 4],
			"I59": [3, 5, 1], "I510": [3, 5, 2], "I511": [3, 5, 3], "I512": [3, 5, 4],
			"I61": [3, 6, 1], "I62": [3, 6, 2], "I63": [3, 6, 3], "I64": [3, 6, 4],
			"I65": [3, 7, 1], "I66": [3, 7, 2], "I67": [3, 7, 3], "I68": [3, 7, 4],
			"I69": [3, 8, 1], "I610": [3, 8, 2], "I611": [3, 8, 3], "I612": [3, 8, 4],
			"I72": [3, 9, 1], "I74": [3, 9, 2], "I76": [3, 9, 3], "I78": [3, 9, 4],
			"I513": [3, 10, 4], "I613": [3, 10, 3], "I712": [3, 10, 2], "I710": [3, 10, 1],
		}

		# Getting a combined list of all stirrers
		self.motors = {**self.cell_motors, **self.interface_motors} 

		# this matrix stores if the motors are enabled (1) or disabled (0)
		# before writting to serial we check this to not sent writes not needed
		self.matrix = {

			# Port_1(satu)
			"C11": 0, "C21": 0, "C31": 0, "C41": 0,
			"C12": 0, "C22": 0, "C32": 0, "C42": 0,
			"C13": 0, "C23": 0, "C33": 0, "C43": 0,
			"C14": 0, "C24": 0, "C34": 0, "C44": 0,
			"C15": 0, "C25": 0, "C35": 0, "C45": 0,
			"C16": 0, "C26": 0, "C36": 0, "C46": 0,
			"C17": 0, "C27": 0, "C37": 0, "C47": 0,

			# Port_2(dua)
			"C51": 0, "C61": 0, "C71": 0,
			"C52": 0, "C62": 0, "C72": 0,
			"C53": 0, "C63": 0, "C73": 0,
			"C54": 0, "C64": 0, "C74": 0,
			"C55": 0, "C65": 0, "C75": 0,
			"C56": 0, "C66": 0, "C76": 0,
			"C57": 0, "C67": 0, "C77": 0,

			# Port_3(tiga)
			"I11": 0,  "I12": 0,  "I13": 0, "I14": 0,
			"I15": 0,  "I16": 0,  "I17": 0, "I18": 0,
			"I19": 0,  "I110": 0, "I111": 0, "I112": 0,
			"I21": 0,  "I22": 0,  "I23": 0, "I24": 0,
			"I25": 0,  "I26": 0,  "I27": 0, "I28": 0,
			"I29": 0,  "I210": 0, "I211": 0, "I212": 0,
			"I31": 0,  "I32": 0,  "I33": 0, "I34": 0,
			"I35": 0,  "I36": 0,  "I37": 0, "I38": 0,
			"I39": 0,  "I310": 0, "I311": 0, "I312": 0,
			"I113": 0, "I213": 0, "I313": 0,
			"I48": 0,  "I410": 0, "I412": 0,

			# Port_4(empat)
			"I41": 0,  "I42": 0,  "I43": 0,  "I44": 0,
			"I45": 0,  "I46": 0,  "I47": 0,
			"I49": 0,  "I411": 0, "I413": 0,
			"I51": 0,  "I52": 0,  "I53": 0,  "I54": 0,
			"I55": 0,  "I56": 0,  "I57": 0,  "I58": 0,
			"I59": 0,  "I510": 0, "I511": 0, "I512": 0,
			"I61": 0,  "I62": 0,  "I63": 0,  "I64": 0,
			"I65": 0,  "I66": 0,  "I67": 0,  "I68": 0,
			"I69": 0,  "I610": 0, "I611": 0, "I612": 0,
			"I72": 0,  "I74": 0,  "I76": 0,  "I78": 0,
			"I513": 0, "I613": 0, "I712": 0, "I710": 0,
			}


	def __del__(self):
		"""
			Disables all the motors.
		"""
		self.disable_all()
		for serial_obj in self.ser.values():
			serial_obj.close()
			del serial_obj


	def close(self):
		"""
			Disables all motors and close the seial communication.
		"""
		self.disable_all()
		for serial_obj in self.ser.values():
			serial_obj.close()
			del serial_obj


	def activate_motor(self, motor_code, direction=0, speed=90):
		"""
			Activates a motor based on the given input arguments.
			Speed : usually refers to the PWM levels.
		"""

		arduino, shield, motor = self.motors[motor_code] # get shield and motor 
		
		if self.matrix[motor_code] < 1 and speed > 0: # we need to activate it

			# Motors needs to be started at higher PWM.
			command = "A%d M%d D%d S255\n" % (shield, motor, direction)
			time.sleep(0.1)	# Sleeping time for 100 ms.
			
			# Setting the desired speed
			command += "A%d M%d D%d S%d\n" % ( shield, motor, direction, speed )
			
			self.matrix[motor_code] = 1 # mark it as enabled
			self.ser[arduino].write(command.encode()) # encode helps program run 

		elif self.matrix[motor_code] < 1 and speed == 0: # we keep it disabled (it's off with 0 speed)
			pass

		elif self.matrix[motor_code] > 0 and speed > 0: # just update speed
			command = "A%d M%d D%d S%d\n" % ( shield, motor, direction, speed )
			self.ser[arduino].write(command.encode())

		elif self.matrix[motor_code] > 0 and speed == 0: # we disable it (on with no speed)
			self.disable_motor(motor_code)

		else:
			print("Motor not responding | Something is WRONG") 


	def activate_cell_all(self, direction=0, speed=90):
		"""
			Activates all interfacial motors at a given PWM level
		"""
		for key, value in self.cell_motors.items(): 
			self.activate_motor(key, direction, speed)
			self.ser[value[0]].flush() #flush variables


	def activate_interface_all(self, direction=0, speed=127):
		"""
			Activates all interfacial motors at a given PWM level
		"""
		for key, value in self.interface_motors.items(): 
			self.activate_motor(key, direction, speed)
			self.ser[value[0]].flush() #flush variables


	def activate_all(self, direction=0, speed=20):
		"""
			Activates all motors at a given PWM level
		"""

		for key, value in self.motors.items(): 
			self.activate_motor(key, direction, speed)
			self.ser[value[0]].flush() #flush variables


	def activate_cell_neighbours(self, cell, nn=4, direction=0, speed=150):
		"""
			Activates all interfacial stirrers for a given cell stirrer ID.
		"""
		i, j = list(map(int, list(cell)[1:3]))
		self.neigh = [[i, 2*j-2], [i, 2*j-1], [i, 2*j], [i-1, 2*j-1]]
		
		# Creating list of surrounding interfacial stirrers
		self.n_list = []

		for i in range(nn):
			self.n_list.append("I"+"".join(str(x) for x in self.neigh[i]))

		# Activating Interfacial stirrers
		for i in self.n_list:
			try:
				self.activate_motor(i, direction, speed)
			except KeyError:
				continue


	def disable_motor(self, motor_code):
		"""
			Disable a motor with the given address.
		"""
		arduino, shield, motor = self.motors[motor_code]
		command = "A%d M%d D0 S0\n" % ( shield, motor )

		if self.matrix[motor_code] > 0: # so it was enabled
			self.ser[arduino].write(command.encode())
			self.matrix[motor_code] = 0 # mark it disabled
			
			
	def disable_all_cells(self):
		"""
			Disables all cell motors.
		"""
		for key in self.cell_motors.keys():
			self.disable_motor(key)


	def disable_all(self):
		"""
			Disables all motors.
		"""
		for key in self.motors.keys():
			self.disable_motor(key)


	def rand_pattern(self, n_cells, activate_neighbours=False, direction=0, speed=20):
		"""
			Creates a random pattern of activated cell stirrers over the whole array.
			n_cells : Number of random cells to be activated.
			
		"""
		# Deactivate previously activated cells
		self.disable_all_cells()
		# time.sleep(5)
		# Randomly shuffling the list of cell stirrers

		# random.seed(time.time()) random function took out to global variable
		self.cell_list = ["C" + str(x) + str(y) for x in range(1,self.ncells_X+1) for y in range(1,self.ncells_Y+1)]
		random.shuffle(self.cell_list)
		
		# Selecting cells from the random shuffle
		self.random_cells = self.cell_list[:n_cells]

		# Activating Cells
		[self.activate_motor(i, direction, speed) for i in self.random_cells]

		# Activating Neighbours
		if activate_neighbours == True:
			[self.activate_cell_neighbours(i) for i in self.random_cells]


if __name__ == "__main__":
	arduino_dict = {
		0: "/dev/BZ_satu",
		1: "/dev/BZ_dua",
		2: "/dev/BZ_tiga",
		3: "/dev/BZ_empat"
		}
	b = BZBoard(port_dict=arduino_dict)

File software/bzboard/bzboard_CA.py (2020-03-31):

# ---------------------------------------------------------------------------- #
# --------------- ONE DIMENSIONAL BZ PLATFORM 1 X 7 CONTROLLER --------------- #
# ---------------------------------------------------------------------------- #


"""
	Controls BZ Board using Serial Interface. Each motor can be addressed individually.
    Cell Stirrers: AC
    Interfacial Stirrers: IF
	The 1 x 7 Platform with interface hsa the following nomenclature:

	+ --------------------------------------------------------------+
	|AC1-(IF1)-AC2-(IF2)-AC3-(IF3)-AC4-(IF4)-AC5-(IF5)-AC6-(IF6)-AC7|
	+---------------------------------------------------------------+

"""

import serial, time, json, random, csv
from datetime import datetime
from random import randint, choice
import json, os

class BZBoard:


    def __init__(self, port): # creates objects to pass through function for each self

        self.ser = serial.Serial(port, 9600, timeout=120)
        time.sleep(2) # serial docs recommend a wait just after connection
        self.ser.flush(); self.ser.flushInput(); self.ser.flushOutput();

        #   This is an attempt to change the script for our system
        #   Since Adafruit goes by binary naming, the 'adafruit_shield' below tells the jumper 
        #   setting of adafruit, we have from 0000(being 0)- 1001(being 9)
        self.motors = { # [adafruit_shield, motor]

            "IF1":[0,1],"IF2":[0,2],"IF3":[0,3],"IF4":[0,4],"IF5":[1,1], "IF6":[1,2],
            "AC1":[2,1],"AC2":[2,2],"AC3":[2,3],"AC4":[2,4],"AC5":[3,1],"AC6":[3,2],"AC7":[3,3]
            }

        # this matrix stores if the motors are enabled (1) or disabled (0)
        # before writting to serial we check this to not sent writes not needed
        self.matrix = { 
            "IF1":0,"IF2":0,"IF3":0,"IF4":0,"IF5":0,"IF6":0,
            "AC1":0,"AC2":0,"AC3":0,"AC4":0,"AC5":0,"AC6":0,"AC7":0,
            }
    

    def __del__(self):

        self.disable_all()
        self.ser.close()
        del self.ser
        # disables all motors and clears variables


    def close(self):

        self.disable_all()
        self.ser.close()
        del self.ser
        # seems to do the same 


    def pattern_from_file(self, patternfile):

        with open(patternfile) as f:
            return json.load(f)


    def activate_motor(self, motor_code, direction=0, speed=100):
        ''' code as in A1 or C2 as marked in the actual board. See the dict motors'''

        shield, motor = self.motors[motor_code] # get shield and motor 
        
        # because sometimes we can send here a speed 0 to disable it
        # the following if will be longer than expected
        if self.matrix[motor_code] < 1 and speed > 0: # we need to activate it
            # The following line is a dirty trick. Some of the motors need to be
            # kickstarted at a higher speed
            command = "A%d M%d D%d S255\n" % (shield, motor, direction)
            # and then we send the desired speed
            command += "A%d M%d D%d S%d\n" % ( shield, motor, direction, speed )
            self.matrix[motor_code] = 1 # mark it as enabled
            self.ser.write(command.encode()) # encode helps program run 

        elif self.matrix[motor_code] < 1 and speed == 0: # we keep it disabled (it's off with 0 speed)
            pass

        elif self.matrix[motor_code] > 0 and speed > 0: # just update speed
            command = "A%d M%d D%d S%d\n" % ( shield, motor, direction, speed )
            self.ser.write(command.encode())

        elif self.matrix[motor_code] > 0 and speed == 0: # we disable it (on with no speed)
            self.disable_motor(motor_code)

        else:
            print("something bad happened when updating a motor") # broken


    def activate_all(self, direction=0, speed=100):

        for key in self.motors.keys(): # set to min stiring speed 
            self.activate_motor(key, direction, speed)
            self.ser.flush() #flush variables


    def activate_pattern(self, pattern, speed=None):

        for i in pattern:
            _, _, speed = self.motors[i] 

            if pattern[i] == 1:
                self.activate_motor(i, speed*2) # x5 before
            else:
                self.activate_motor(i, speed*0) # x1 before if motor is off speed off

    
    def activate_pattern_defined_speed(self, pattern, speed):
        #same as above but speed is defined and costatn across motors
        for i in pattern:
            _, _, speed = self.motors[i] 

            if pattern[i] == 1:
                self.activate_motor(i, speed) # x5 before
            else:
                self.activate_motor(i, speed*0) # x1 before if motor is off speed off            
    

    def activate_rand_all(self, filename): #BZ2 won't be using this, at least for now
        '''Activate a random pattern - each motor at a random speed - and append
        this random configuration to the end of the file filename'''

        # random 5*5 speed
        rand_speed = { 
                    "A1":randint(0,255),"A2":randint(0,255),"A3":randint(0,255),"A4":randint(0,255),"A5":randint(0,255),
                    "B1":randint(0,255),"B2":randint(0,255),"B3":randint(0,255),"B4":randint(0,255),"B5":randint(0,255),
                    "C1":randint(0,255),"C2":randint(0,255),"C3":randint(0,255),"C4":randint(0,255),"C5":randint(0,255),
                    "D1":randint(0,255),"D2":randint(0,255),"D3":randint(0,255),"D4":randint(0,255),"D5":randint(0,255),
                    "E1":randint(0,255),"E2":randint(0,255),"E3":randint(0,255),"E4":randint(0,255),"E5":randint(0,255)
                    }

        # enable the motors with the random speeds
        for i in self.motors.keys():
            speed = rand_speed[i]
            self.activate_motor(i, speed)

        self.save_pattern_in_json(rand_speed, filename)
        return rand_speed


    def repeat_rand(self, filename, inspeeds):
        ''' Repeats a random experiment and saves it into the corresponding
        json file'''
    
        # enable the motors with the random speeds
        for i in self.motors.keys():
            speed = inspeeds[i]
            self.activate_motor(i, speed)

        self.save_pattern_in_json(inspeeds, filename)
        return inspeeds


    def activate_rand_single(self, filename):
        '''Activates only 1 motor at a random speed - and append
        this random configuration to the end of the file filename'''

        # first generate dict as before with all 0s
        speeds = { 
                    "A1":0,"A2":0,"A3":0,"A4":0,"A5":0,
                    "B1":0,"B2":0,"B3":0,"B4":0,"B5":0,
                    "C1":0,"C2":0,"C3":0,"C4":0,"C5":0,
                    "D1":0,"D2":0,"D3":0,"D4":0,"D5":0,
                    "E1":0,"E2":0,"E3":0,"E4":0,"E5":0
                    }

        random_motor = choice("ABCDE")+choice("12345") # choice is from random
        speed = randint(0,255)
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
